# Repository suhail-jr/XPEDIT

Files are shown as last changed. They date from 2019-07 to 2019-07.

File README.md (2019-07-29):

# XPEDIT
When you are planning to do an adventure journey or trekking to the wild, it is essential to have a device in your backpack that helps you to understand the environment. For my upcoming adventure journey, i planned to build a device that helps me to monitors temperature, humidity, air pressure, and altitude.

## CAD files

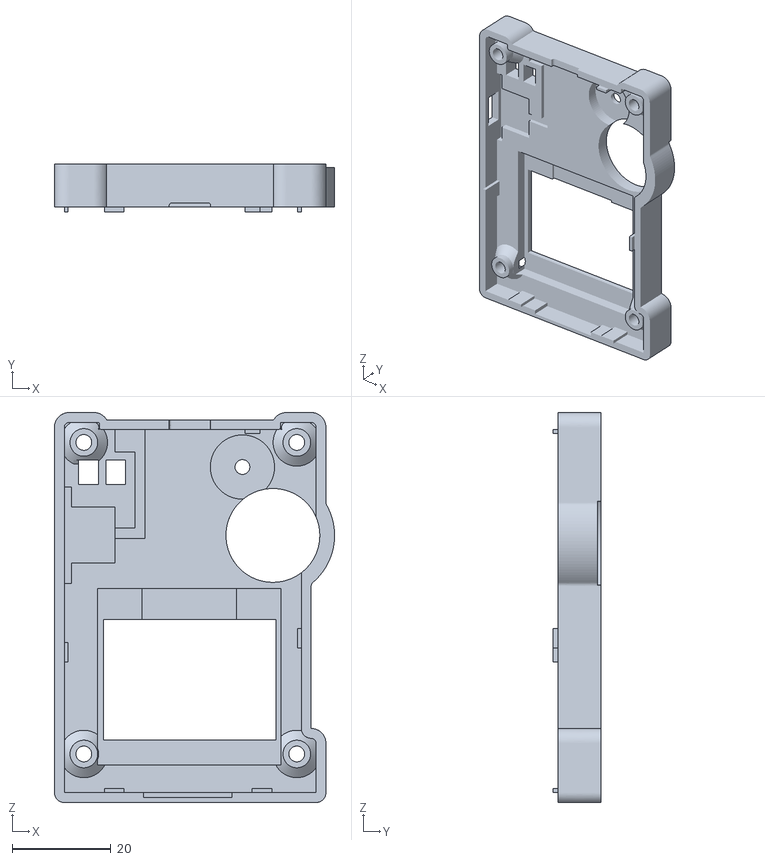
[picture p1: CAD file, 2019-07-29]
3D print/lid.stl
56.7 x 9.77 x 79.0

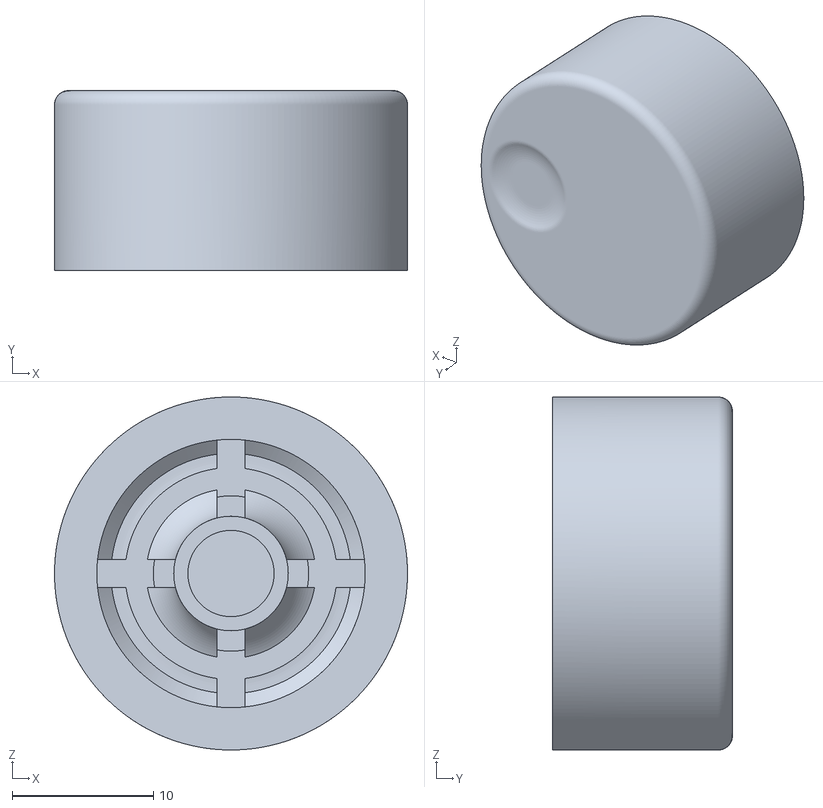
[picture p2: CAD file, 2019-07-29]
3D print/encoder.stl
25.0 x 12.7 x 25.0

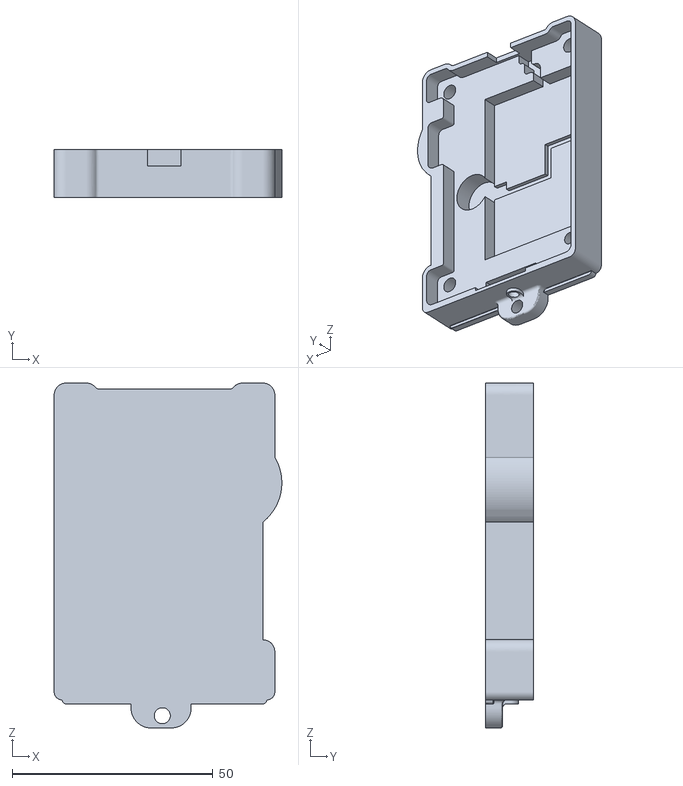
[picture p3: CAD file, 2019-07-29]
3D print/Body.stl
56.7 x 12.0 x 86.0

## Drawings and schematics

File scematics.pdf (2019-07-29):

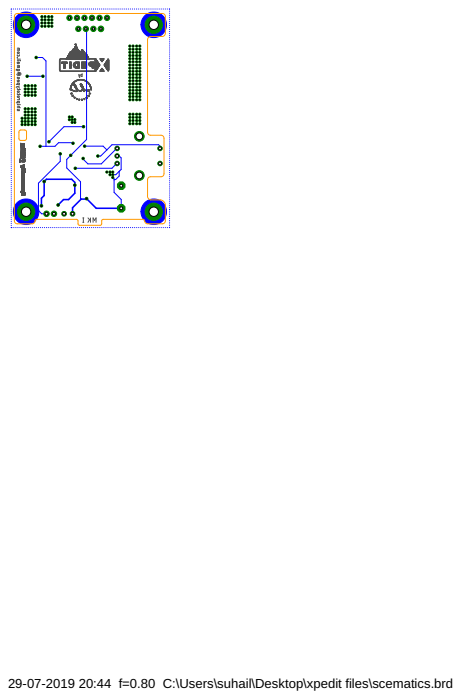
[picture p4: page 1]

29-07-2019 20:44 f=0.80 C:\Users\suhail\Desktop\xpedit files\scematics.brd

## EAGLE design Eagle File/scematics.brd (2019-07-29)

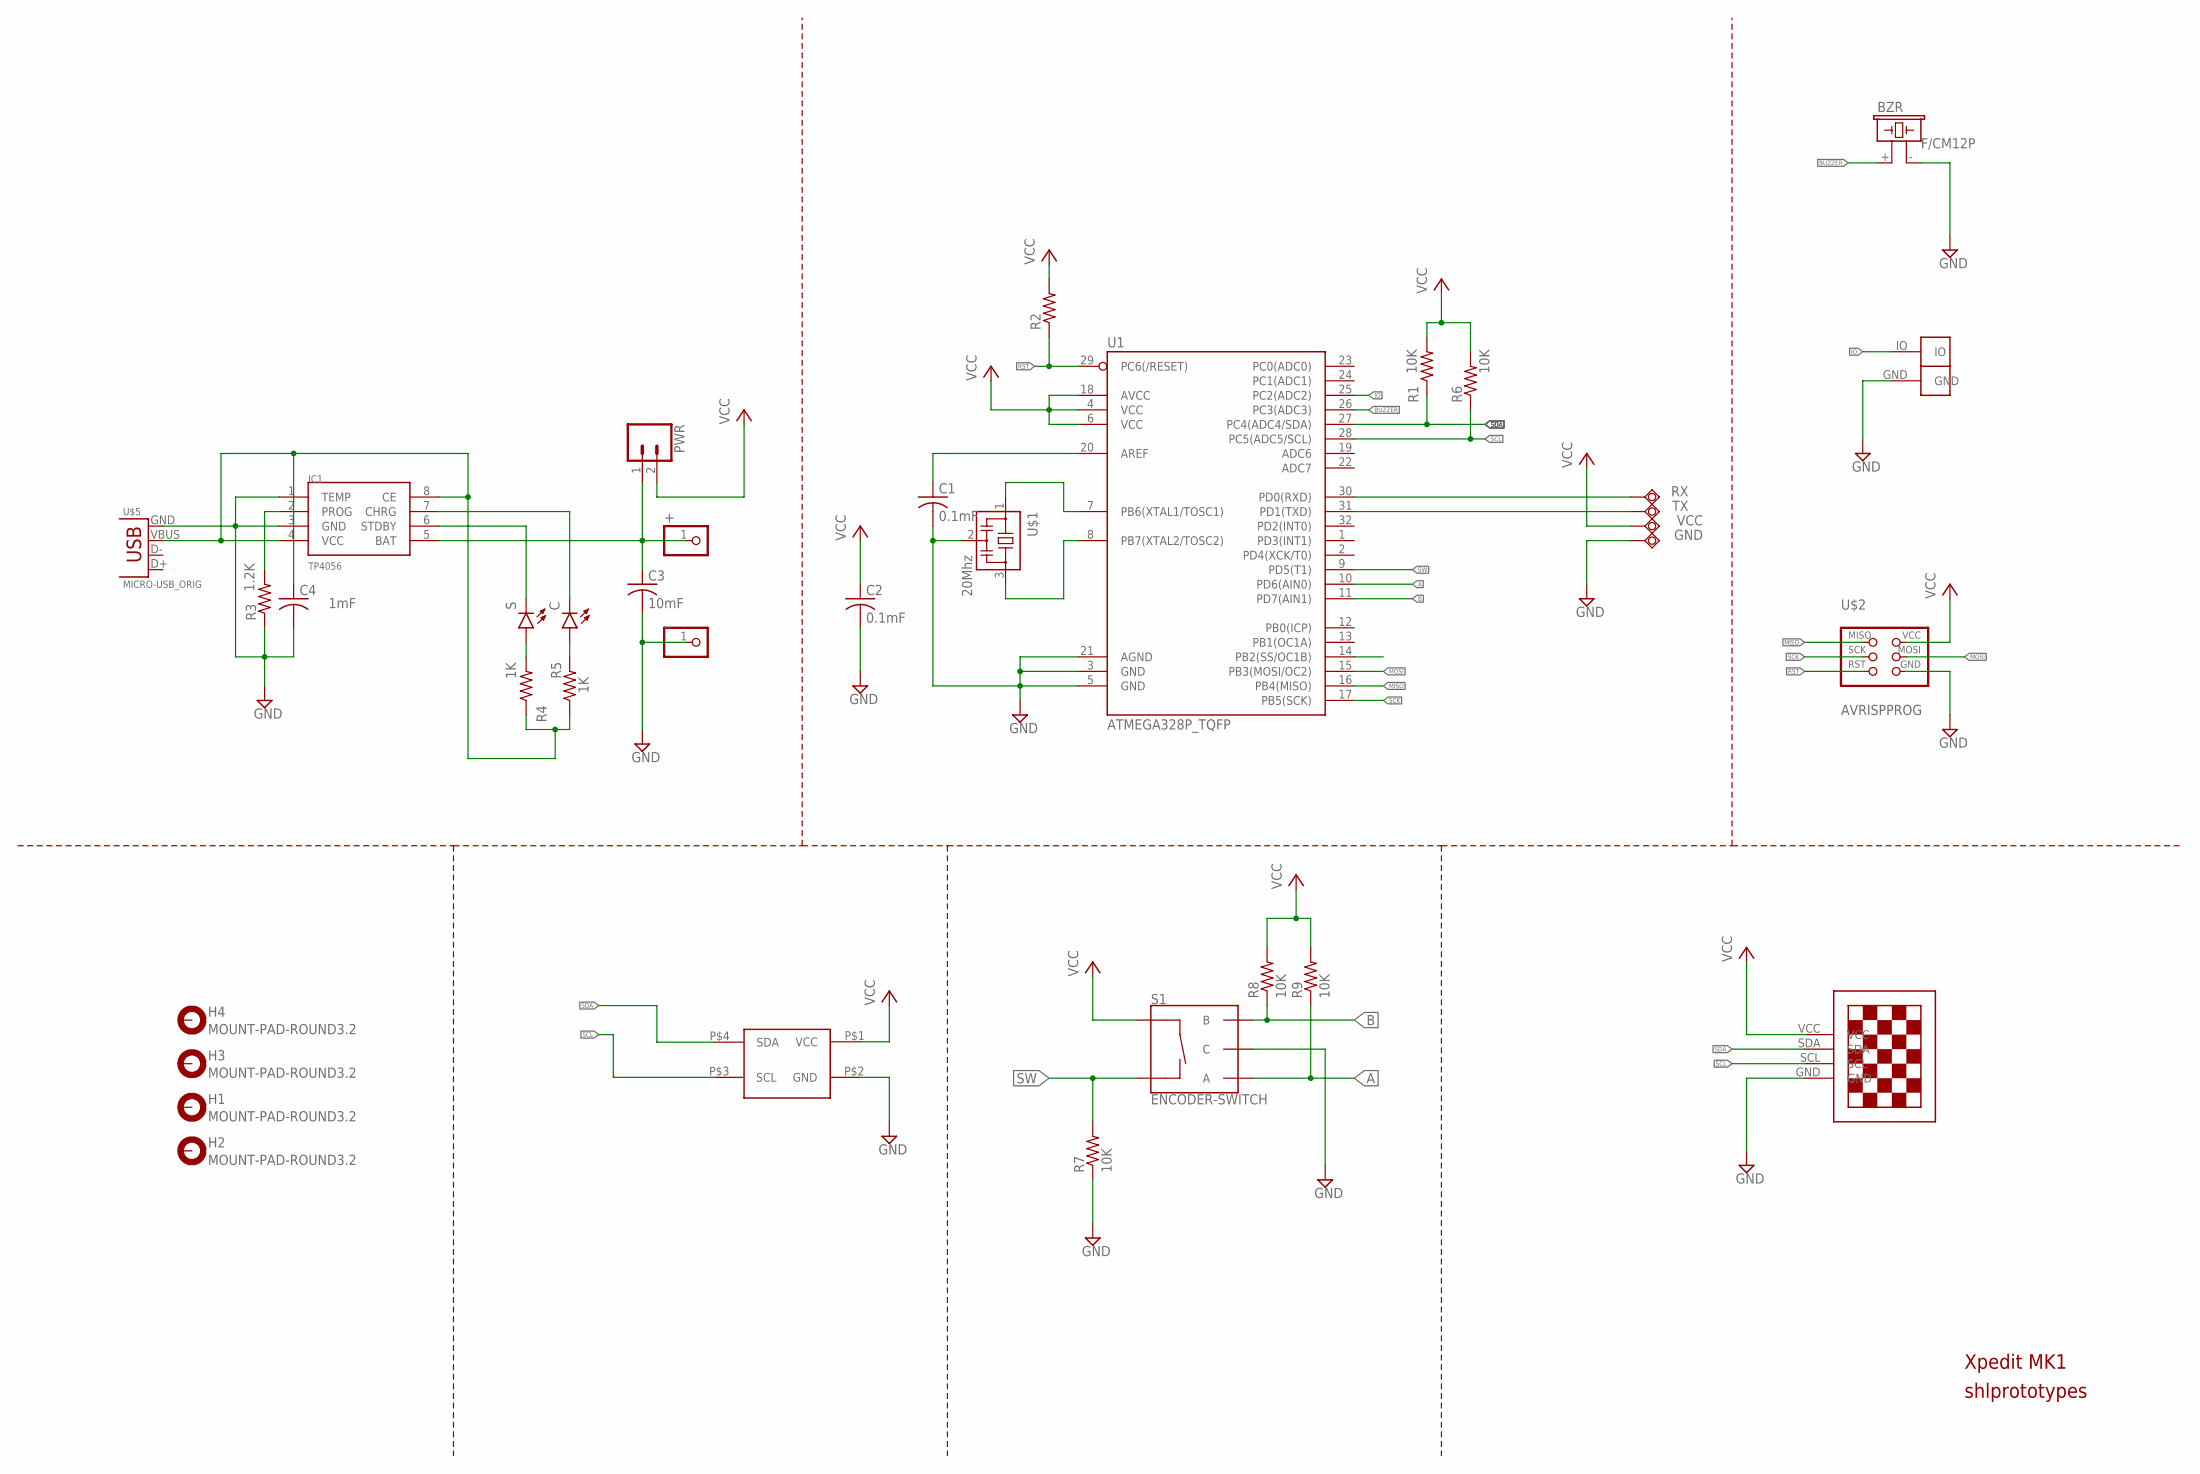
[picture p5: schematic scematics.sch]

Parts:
+: PINHD-1X1; 1X01
BZR: F/CM12P
C: LEDSML0805; SML0805
C1, C2: 0.1mF; C0805
C3: 10mF; C0805
C4: 1mF; C0805
GND: TPSQTP16R; TP16R
H1, H2, H3, H4: MOUNT-PAD-ROUND3.2; 3,2-PAD
IC1: TP4056; SOP-8
PWR: CONN_02; 1X02
R1, R6, R7, R8, R9: 10K; R0805
R2: R-US_R0805; R0805
R3: 1.2K; R0805
R4, R5: 1K; R0805
RX: TPSQTP16R; TP16R
S: LEDSML0805; SML0805
S1: ENCODER-SWITCH; ROTARY_ENC_PLAIN
TAPTIC: VIBRARTOR; VIBRATOR
TX: TPSQTP16R; TP16R
U1: ATMEGA328P_TQFP; TQFP32-08
U$1: 20Mhz; EFOBM
U$2: AVRISPPROG; SMD
U$3: BME280
U$4: 13"OLED13"OLED; 1.3"OLED
U$5: MICRO-USB_ORIG; DX4R005HJ5
VCC: TPSQTP16R; TP16R
_: PINHD-1X1; 1X01

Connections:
A: R9.1, S1.A, U1.10 (PD6(AIN0))
B: R8.1, S1.B, U1.11 (PD7(AIN1))
BUZZER: BZR.+ (1), U1.26 (PC3(ADC3))
CS: U1.14 (PB2(SS/OC1B))
GND: BZR.- (2), C1.2, C2.2, C3.2, C4.2, GND.TP, IC1.1 (TEMP), IC1.3 (GND), R3.1, R7.1, S1.C, TAPTIC.GND, U1.3 (GND), U1.5 (GND), U1.21 (AGND), U$1.2, U$2.6 (GND), U$3.P$2 (GND), U$4.GND, U$5.GND, _.1
IO: TAPTIC.IO, U1.25 (PC2(ADC2))
MISO: U1.16 (PB4(MISO)), U$2.1 (MISO)
MOSI: U1.15 (PB3(MOSI/OC2)), U$2.5 (MOSI)
unnamed: U1.7 (PB6(XTAL1/TOSC1)), U$1.1
unnamed: U1.8 (PB7(XTAL2/TOSC2)), U$1.3
unnamed: RX.TP, U1.30 (PD0(RXD))
unnamed: TX.TP, U1.31 (PD1(TXD))
unnamed: +.1, C3.1, IC1.5 (BAT), PWR.1
unnamed: C1.1, U1.20 (AREF)
unnamed: IC1.2 (PROG), R3.2
unnamed: C4.1, IC1.4 (VCC), IC1.8 (CE), R4.1, R5.1, U$5.VBUS
unnamed: IC1.6 (STDBY), S.C
unnamed: C.C, IC1.7 (CHRG)
unnamed: C.A, R5.2
unnamed: R4.2, S.A
RST: R2.1, U1.29 (PC6(/RESET)), U$2.3 (RST)
SCK: U1.17 (PB5(SCK)), U$2.2 (SCK)
SCL: R6.1, U1.28 (PC5(ADC5/SCL)), U$3.P$3 (SCL), U$4.SCL
SDA: R1.1, U1.27 (PC4(ADC4/SDA)), U$3.P$4 (SDA), U$4.SDA
SW: R7.2, S1.SW-, U1.9 (PD5(T1))
VCC: C2.1, PWR.2, R1.2, R2.2, R6.2, R8.2, R9.2, S1.SW+, U1.4 (VCC), U1.6 (VCC), U1.18 (AVCC), U$2.4 (VCC), U$3.P$1 (VCC), U$4.VCC, VCC.TP

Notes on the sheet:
Xpedit MK1
shlprototypes

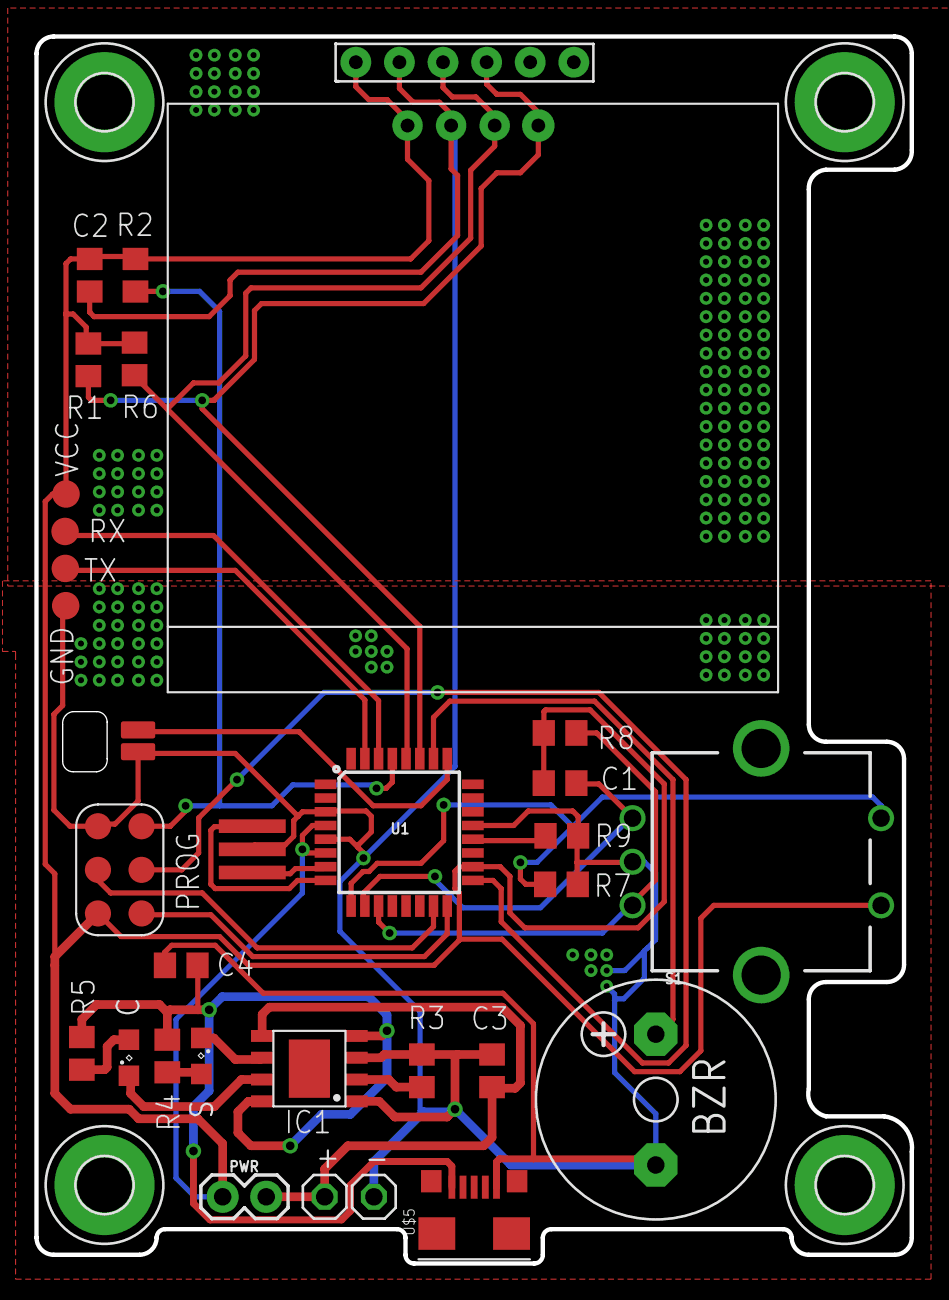
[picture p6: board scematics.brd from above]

Board: 2 copper layers, 51.0 x 71.5 mm, 36 parts (0 on the bottom side), 25 nets.

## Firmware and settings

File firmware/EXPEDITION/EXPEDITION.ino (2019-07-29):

#include<Wire.h>
#include<SPI.h>
#include<Adafruit_Sensor.h>
#include<Adafruit_BME280.h>
#include <Adafruit_GFX.h>
#include <Adafruit_SH1106.h>


#define OLED_RESET 4
Adafruit_SH1106 display(OLED_RESET);
#if (SH1106_LCDHEIGHT != 64)
#error("Height incorrect, please fix Adafruit_SH1106.h!");
#endif

#define LOGO16_GLCD_HEIGHT 9
#define LOGO16_GLCD_WIDTH  9
const unsigned char tempicon[]PROGMEM = {
  0x0, 0x0, 0x0, 0x0,
  0x0, 0x0, 0x0, 0x0,
  0x0, 0x3c, 0x0, 0x0,
  0x0, 0x7c, 0x0, 0x0,
  0x0, 0x7e, 0xfc, 0x0,
  0x0, 0x7e, 0xfe, 0x0,
  0x0, 0x7e, 0x0, 0x0,
  0x0, 0x7e, 0x0, 0x0,
  0x0, 0x7e, 0x70, 0x0,
  0x0, 0x7e, 0xf8, 0x0,
  0x0, 0x7e, 0x0, 0x0,
  0x0, 0x7e, 0x0, 0x0,
  0x0, 0x7e, 0x70, 0x0,
  0x0, 0x7e, 0x70, 0x0,
  0x0, 0x7e, 0x0, 0x0,
  0x0, 0x7e, 0x40, 0x0,
  0x0, 0x7e, 0x60, 0x0,
  0x0, 0x7e, 0x0, 0x0,
  0x0, 0x7e, 0x0, 0x0,
  0x0, 0x7e, 0x0, 0x0,
  0x0, 0xfe, 0x0, 0x0,
  0x1, 0xff, 0x0, 0x0,
  0x3, 0xff, 0x80, 0x0,
  0x3, 0xff, 0x80, 0x0,
  0x3, 0xff, 0xc0, 0x0,
  0x3, 0xff, 0xc0, 0x0,
  0x3, 0xff, 0xc0, 0x0,
  0x3, 0xff, 0x80, 0x0,
  0x1, 0xff, 0x80, 0x0,
  0x1, 0xff, 0x0, 0x0,
  0x0, 0x7c, 0x0, 0x0,
  0x0, 0x0, 0x0, 0x0,
  0x0, 0x0, 0x0, 0x0
};

bool status;

#define SEALEVELPRESSURE_HPA (1013.25)
Adafruit_BME280 bme;


int temp;
int hum;
int alt;
int prsr;

char c_temp[20];
char c_hum[20];
char c_alt[20];
char c_prsr[20];

void setup() {
  status = bme.begin();
  display.begin(SH1106_SWITCHCAPVCC, 0x3C);
  display.display();

  display.clearDisplay();



}

void loop()
{ 
  sensorValue();
  display.clearDisplay();
  disp_frame();
  display_data();

 


}

void sensorValue()
{

  temp = bme.readTemperature(); // *c
  hum = bme.readHumidity();// %
  alt = bme.readAltitude(SEALEVELPRESSURE_HPA);//m
  prsr = bme.readPressure() / 100.0F; //hpa
  itoa(temp, c_temp, 10);
  itoa(temp, c_hum, 10);
  itoa(prsr, c_prsr, 10);
  itoa(alt, c_alt, 10);
  strcat(c_temp, "C");
  strcat(c_hum, "%");
  strcat(c_prsr, "hPa");
  strcat(c_alt, "M");



}

void disp_frame()
{

  display.setTextColor(WHITE);
  display.drawFastVLine( 63, 0, 48, WHITE);
  display.drawFastVLine( 66, 0, 48, WHITE);
  display.drawFastHLine( 0, 48, 63, WHITE);
  display.drawFastHLine( 63, 48, 65, WHITE);

  display.drawFastHLine( 0, 50, 63, WHITE);
  display.drawFastVLine( 63, 50, 14, WHITE);

  display.drawFastHLine( 66, 50, 63, WHITE);
  display.drawFastVLine( 66, 50, 14, WHITE);

  display.setTextSize(1);
  display.setCursor(18, 52);
  display.println("menu");

  display.setTextSize(1);
  display.setCursor(74, 53);
  display.println("bat: 80%");

  display.display();

  //display.drawBitmap(25, 2, tempicon, 10, 15, WHITE);

}
void disp_frame2()
{

  display.setTextColor(WHITE);
  
  display.drawFastHLine( 0, 48, 128, WHITE);


  display.drawFastHLine( 0, 50, 63, WHITE);
  display.drawFastVLine( 63, 50, 14, WHITE);

  display.drawFastHLine( 66, 50, 63, WHITE);
  display.drawFastVLine( 66, 50, 14, WHITE);

  display.setTextSize(1);
  display.setCursor(18, 52);
  display.println("menu");
  display.setTextSize(1);
  display.setCursor(74, 53);
  display.println("bat: 80%");

  display.display();

  //display.drawBitmap(25, 2, tempicon, 10, 15, WHITE);

}

void display_data()
{



  display.setTextSize(1);
  display.setCursor(0, 3);
  display.println("temperatur");
  display.setTextSize(3);
  display.setCursor(5, 20);
  display.println(c_temp);


  display.setTextSize(1);
  display.setCursor(73, 3);
  display.println("humidity");
  display.setTextSize(3);
  display.setCursor(73, 20);
  display.println(c_hum);
  display.display();
  delay(2000);
  display.clearDisplay();

  disp_frame2();



  display.setTextSize(1);
  display.setCursor(33, 3);
  display.println("Air Pressure");
  display.setTextSize(2);
  display.setCursor(20, 25);
  display.println(c_prsr);
 display.display();
  delay(2000);
  display.clearDisplay();
disp_frame2();
  display.setTextSize(1);
  display.setCursor(38, 3);
  display.println("Altitude");
  display.setTextSize(2);
  display.setCursor(40, 25);
  display.println(c_alt);
  display.display();
  delay(2000);

  display.clearDisplay();

}

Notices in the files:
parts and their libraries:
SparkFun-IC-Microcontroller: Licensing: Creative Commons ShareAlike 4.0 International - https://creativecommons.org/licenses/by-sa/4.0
